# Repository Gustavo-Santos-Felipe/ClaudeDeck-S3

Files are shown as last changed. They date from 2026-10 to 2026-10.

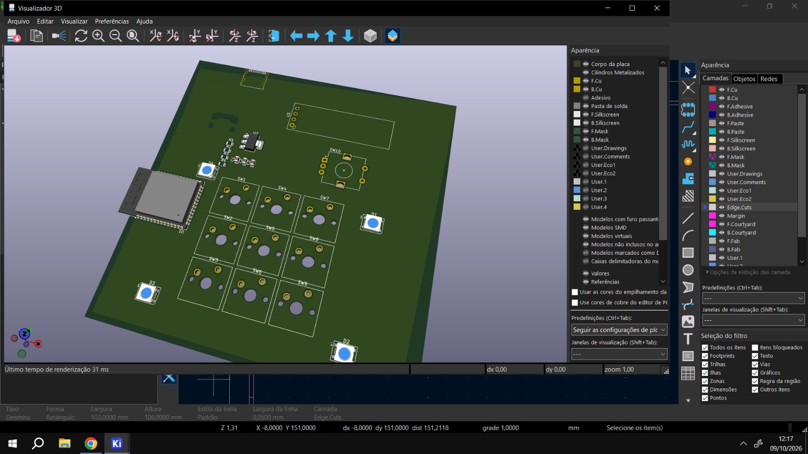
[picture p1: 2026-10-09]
render_3d.png

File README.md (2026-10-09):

# ClaudeDeck-S3
An open-source, ESP32-S3-powered mechanical macropad designed for developer productivity and Claude AI integration. Features 10 hot-swappable mechanical switches with per-key RGB backlighting, a rotary encoder, and an I2C OLED display for real-time status and shortcut navigation.
Render da Placa
20250326_132614-1148x864

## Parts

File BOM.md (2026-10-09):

# ClaudeDeck S3 – bill of materials

<!-- Generated by Half Life from project cmuv6cyex0dys01smc1ebw71v. Edits here are overwritten on the next sync. -->
<!-- Generated: 2026-10-09T17:57:54.359Z -->

> [!NOTE]
> This parts list is mirrored from [Half Life](https://halflife.hackclub.com). Editing it here will not change the platform's copy, and the next sync overwrites this file.

| Week | Tier | Parts funding |
| --- | --- | --- |
| Week 1 | Tier 2 | $65.00 |

| Part | What it's for | Qty | Unit | Total | Vendor |
| --- | --- | --- | --- | --- | --- |
| [ESP32-S3-WROOM-1 / ESP32-S3 N16R8 Dev Board](https://www.mercadolivre.com.br/esp32s3-n16r8-com-16mb-flash-8mb-psram--brinde-cabo-usb/up/MLBU3759855210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) | Main microcontroller, Wi-Fi, and processing logic | 1 | $16.00 | $16.00 | [Mercado Livre BR](https://www.mercadolivre.com.br/esp32s3-n16r8-com-16mb-flash-8mb-psram--brinde-cabo-usb/up/MLBU3759855210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) |
| [Switches](https://www.mercadolivre.com.br/p/MLB2091173212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) | Mechanical keyboard switches for the 3x3 matrix | 1 | $6.00 | $6.00 | [Mercado Livre BR](https://www.mercadolivre.com.br/p/MLB2091173212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) |
| [OLED Display 0.91 inch I2C (128x32)](https://produto.mercadolivre.com.br/MLB-4553164164-display-oled-128x32-pixel-091-polegadas-4-pinos-i2c-_JM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) | Screen to display real-time status and menus | 1 | $11.50 | $11.50 | [Mercado Livre BR](https://produto.mercadolivre.com.br/MLB-4553164164-display-oled-128x32-pixel-091-polegadas-4-pinos-i2c-_JM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) |
| [WS2812B SMD 5050 RGB LEDs](https://www.mercadolivre.com.br/kit-100-unidades-chip-led-rgb-5050-alto-brilho-chip-rgb/up/MLBU1424762403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) | Programmable RGB backlighting | 4 | $5.00 | $20.00 | [Mercado Livre BR](https://www.mercadolivre.com.br/kit-100-unidades-chip-led-rgb-5050-alto-brilho-chip-rgb/up/MLBU1424762403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) |
| [USB-c module](https://www.mercadolivre.com.br/conector-usb-c-31-16-pin-femea-modulo-para-soldagem-pcb/up/MLBU3682374993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) | power distribuic | 1 | $3.00 | $3.00 | [Mercado Livre BR](https://www.mercadolivre.com.br/conector-usb-c-31-16-pin-femea-modulo-para-soldagem-pcb/up/MLBU3682374993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) |
| [encolder](https://www.mercadolivre.com.br/10-encoder-rotativo-com-chave-5-terminais-potenciometro-ec11/up/MLBU1466437144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) | eyboard switches | 1 | $8.00 | $8.00 | [Mercado Livre BR](https://www.mercadolivre.com.br/10-encoder-rotativo-com-chave-5-terminais-potenciometro-ec11/up/MLBU1466437144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) |
| **Parts subtotal** | — | — | — | **$64.50** | — |
| **Tax & shipping** | — | — | — | **$0.00** | — |
| **Total** | — | — | — | **$64.50** | — |

$0.50 left of the tier's funding.

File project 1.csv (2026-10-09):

Id | Designador | Footprint | Quantidade | Designação | Fornecedor e referência
1 | C1, C2 | C_0805_2012Metric | 2 | 10µF
2 | C3 | C_0805_2012Metric | 1 | C
3 | D1, D2, D3, D4 | LED_WS2812B_PLCC4_5.0x5.0mm_P3.2mm | 4 | WS2812B
4 | J1 | USB_C_Receptacle_HRO_TYPE-C-31-M-12 | 1 | USB_C_Receptacle_USB2.0_14P
5 | R1, R2 | R_0805_2012Metric | 2 | 5.1kΩ
6 | R3 | R_0805_2012Metric | 1 | R_US
7 | R4 | R_0805_2012Metric | 1 | 330Ω
8 | SW1, SW2, SW3, SW4, SW5, SW6, SW7, SW8, SW9 | SW_Cherry_MX_1.00u_PCB | 9 | SW_Push
9 | SW10 | RotaryEncoder_Alps_EC12E-Switch_Vertical_H20mm | 1 | RotaryEncoder_Switch
10 | U1 | ESP32-S3-WROOM-1 | 1 | ESP32-S3-WROOM-1
11 | U2 | SOT-223-3_TabPin2 | 1 | AMS1117-3.3
12 | U3 | ER_OLEDM0.91_1x-I2C | 1 | ER_OLEDM0.91_1x-I2C

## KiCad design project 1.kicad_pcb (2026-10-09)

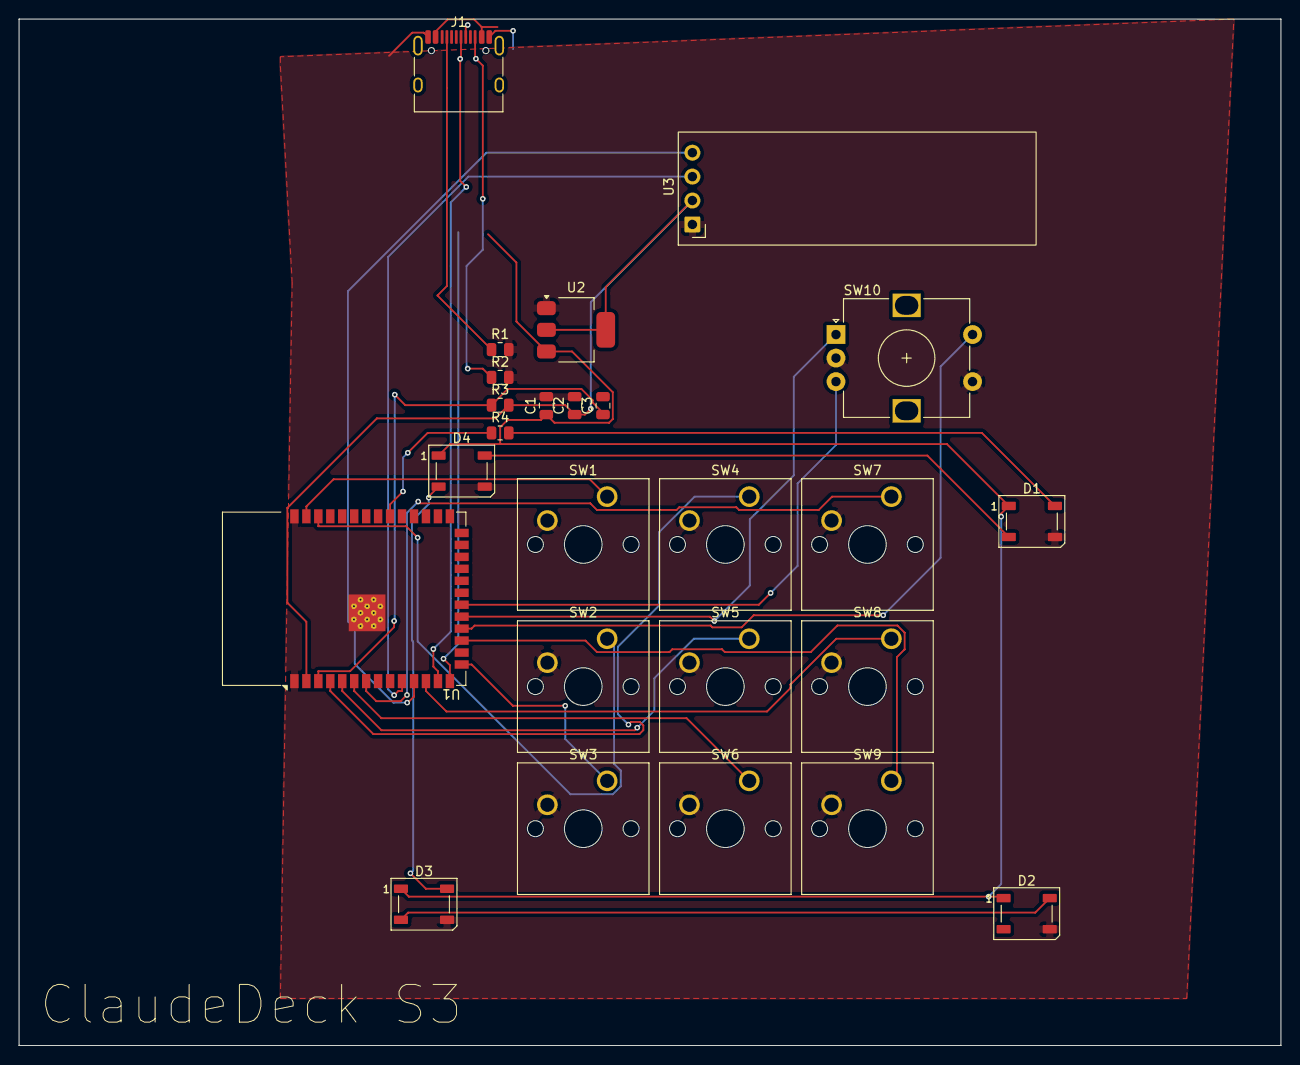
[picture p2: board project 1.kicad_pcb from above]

Board: 2 copper layers, 134.0 x 109.0 mm, 25 parts (0 on the bottom side), 27 nets.

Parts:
C1, C2: 10µF; C_0805_2012Metric
C3: C; C_0805_2012Metric
D1, D2, D3, D4: WS2812B; LED_WS2812B_PLCC4_5.0x5.0mm_P3.2mm
J1: USB_C_Receptacle_USB2.0_14P; USB_C_Receptacle_HRO_TYPE-C-31-M-12
R1, R2: 5.1kΩ; R_0805_2012Metric
R3: R_US; R_0805_2012Metric
R4: 330Ω; R_0805_2012Metric
SW1, SW2, SW3, SW4, SW5, SW6, SW7, SW8, SW9: SW_Push; SW_Cherry_MX_1.00u_PCB
SW10: RotaryEncoder_Switch; RotaryEncoder_Alps_EC12E-Switch_Vertical_H20mm
U1: ESP32-S3-WROOM-1
U2: AMS1117-3.3; SOT-223-3_TabPin2
U3: ER_OLEDM0.91_1x-I2C

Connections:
/+3V3: C2.1, R3.2, U1.2 (3V3), U2.2 (VO), U3.2 (VCC)
/+5V: C1.1, D1.1 (VDD), D2.1 (VDD), D3.1 (VDD), D4.1 (VDD), J1.A4 (VBUS), J1.A9 (VBUS), J1.B4 (VBUS), J1.B9 (VBUS), U2.3 (VI)
/DOUT1: D1.2 (DOUT), D4.4 (DIN)
/DOUT2: D3.4 (DIN), D4.2 (DOUT)
/DOUT3: D2.4 (DIN), D3.2 (DOUT)
/IO1: SW1.1, U1.39 (IO1)
/IO2: SW2.1, U1.38 (IO2)
/IO3: SW3.1, U1.15 (IO3)
/IO4: SW4.1, U1.4 (IO4)
/IO5: SW5.1, U1.5 (IO5)
/IO6: SW6.1, U1.6 (IO6)
/IO7: SW7.1, U1.7 (IO7)
/IO8: SW8.1, U1.12 (IO8)
/IO9: SW9.1, U1.17 (IO9)
/IO10: SW10.S1, U1.18 (IO10)
/IO11: SW10.A, U1.19 (IO11)
/IO12: SW10.B, U1.20 (IO12)
GND: C1.2, C2.2, C3.2, D1.3 (VSS), D2.3 (VSS), D3.3 (VSS), D4.3 (VSS), J1.A1 (GND), J1.A12 (GND), J1.B1 (GND), J1.B12 (GND), R1.2, R2.2, SW1.2, SW2.2, SW3.2, SW4.2, SW5.2, SW6.2, SW7.2, SW8.2, SW9.2, SW10.C, SW10.S2, U1.1 (GND), U1.40 (GND), U1.41 (GND), U2.1 (GND), U3.1 (GND)
unnamed: D1.4 (DIN), R4.2
unnamed: J1.A5 (CC1), R1.1
unnamed: J1.B5 (CC2), R2.1
unnamed: C3.1, R3.1, U1.3 (EN)
unnamed: U1.10 (IO17), U3.3 (SCL)
unnamed: U1.11 (IO18), U3.4 (SDA)
unnamed: R4.1, U1.32 (IO39)
unnamed: J1.B6 (D+), U1.14 (USB_D+)
unnamed: J1.A7 (D-), U1.13 (USB_D-)

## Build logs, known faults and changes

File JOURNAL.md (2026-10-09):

# ClaudeDeck S3 – devlog

<!-- Generated by Half Life from project cmuv6cyex0dys01smc1ebw71v. Edits here are overwritten on the next sync. -->
<!-- Generated: 2026-10-09T15:54:22.577Z -->

> [!NOTE]
> This devlog is mirrored from [Half Life](https://halflife.hackclub.com). Editing it here will not change the platform's copy, and the next sync overwrites this file.

> An open-source, ESP32-S3-powered mechanical macropad designed for developer productivity and Claude AI integration. Features 10 hot-swappable mechanical switches with per-key RGB backlighting, a rotary encoder, and an I2C OLED display for real-time status and shortcut navigation.

| Week | Tier | Hours logged | Entries |
| --- | --- | --- | --- |
| Week 1 | Tier 2 | 16h | 3 |

## Contents

1. [2026-10-05 – Hi community. First, I went through a quick tutorial, since I'm more used to EasyEDA rsrsrs.](#2026-10-05-hi-community-first-i-went-through-a-quick-tutoria)
2. [2026-10-06 – The journey of the past 5 hours has been one of pure dedication to hardware design. What started as an idea for a custom ESP32-S3 macropad began to take real shape in KiCad. The first major milestone](#2026-10-06-the-journey-of-the-past-5-hours-has-been-one-of-p)
3. [2026-10-09 – Building the ClaudeDeck S3: From Initial Routing to a Finished PCB](#2026-10-09-building-the-claudedeck-s3-from-initial-routing-t)

## Design

### 2026-10-05 – Hi community. First, I went through a quick tutorial, since I'm more used to EasyEDA rsrsrs.

**6h**

Hi community. First, I went through a quick tutorial, since I'm more used to EasyEDA rsrsrs.

WhatsApp Image 2026-10-05 at 21.53.50
WhatsApp Image 2026-10-05 at 22.54.29

I started this session aiming to lay out the core components of my ESP32-S3 macropad. Initially, I made a mistake by selecting the bare ESP32-S3 SoC instead of the module. I realized my mistake and reorganized the layout to use the ESP32-S3-WROOM-1 module for easier soldering later.

WhatsApp Image 2026-10-05 at 21.53.50
Next, I tackled the power delivery, connecting a USB-C receptacle to an AMS1117-3.3 LDO. I thought just connecting VBUS and GND was enough, but I learned a crucial hardware lesson today: if someone uses a USB-C to USB-C cable (like a Mac charger), it won't provide 5V unless it detects a device! To solve this, I had to add two separate 5.1kΩ pull-down resistors to the CC1 and CC2 pins.

WhatsApp Image 2026-10-05 at 21.54.15
I also learned that voltage regulators are highly unstable without filters, so I added 10uF ceramic capacitors to the input and output of the LDO (I actually almost used a condenser microphone symbol by accident before fixing it!). To ensure the ESP32 boots properly, I wired a 10kΩ pull-up resistor and a 1uF capacitor to the EN pin.

WhatsApp Image 2026-10-05 at 22.18.10
Finally, I started mapping the mechanical switches using Net Labels (IO1 to IO9) to keep the schematic clean and avoid having messy wires crossing everywhere.

WhatsApp Image 2026-10-05 at 22.57.40

WhatsApp Image 2026-10-05 at 23.07.08

### 2026-10-06 – The journey of the past 5 hours has been one of pure dedication to hardware design. What started as an idea for a custom ESP32-S3 macropad began to take real shape in KiCad. The first major milestone

**5h**

The journey of the past 5 hours has been one of pure dedication to hardware design. What started as an idea for a custom ESP32-S3 macropad began to take real shape in KiCad. The first major milestone was the electrical schematic: integrating the microcontroller, mapping the OLED display, configuring the rotary encoder, and ensuring that the data communication for the LED cascade was perfect.

WhatsApp Image 2026-10-06 at 07.45.08

WhatsApp Image 2026-10-06 at 08.03.31
When transitioning to the physical board design, I faced the classic footprint conflicts. I debugged and resolved each one of them with a clear goal in mind: to ensure that this is a genuinely open-source and easy-to-replicate project. To achieve this, I made a point of standardizing the selection with the industry's most universal components, ensuring compatibility with Cherry MX switches and common SMD resistors.

WhatsApp Image 2026-10-06 at 08.28.27

WhatsApp Image 2026-10-06 at 08.16.28
The most satisfying moment was undoubtedly updating the PCB and successfully placing all the components in the editor without a single error. The logical foundation is solid and validated. The next step is organizing the physical layout of the panel and starting the track routing. The effort in electronics always pays off!

WhatsApp Image 2026-10-06 at 08.45.14

### 2026-10-09 – Building the ClaudeDeck S3: From Initial Routing to a Finished PCB

**5h**

Building the ClaudeDeck S3: From Initial Routing to a Finished PCB
The project began with the goal of designing an open-source, custom 3x3 macropad. The first steps in KiCad involved organizing the switch matrix and routing the initial copper traces. However, the early design lacked a crucial element. As noted in the log, the circuit was "sem MALHA GND" (without a GND copper pour). It was missing the copper fill that acts as a ground plane, which is essential for signal integrity and board stability.

WhatsApp Image 2026-10-07 at 15.57.10
After connecting the components, the 3D viewer was used to check the physical appearance of the board. The software rendered a massive, disproportionate green fiberglass board. The entire circuit and the USB-C connector were surrounded by excessive empty space. This happened because the original board outline was too large. If manufactured in this state, the USB cable would not physically reach the connector.

WhatsApp Image 2026-10-09 at 12.19.22
To fix this, the oversized outline was deleted and a new, compact border was drawn closely around the copper zones. For the board to be practical, mechanical constraints also had to be addressed. This progress was marked by the update stating the board was "AGORA COM FUROS DE FIXAÇÃO" (now with mounting holes). Adding these four corner holes ensured the PCB could be properly secured inside its future 3D-printed enclosure.

WhatsApp Image 2026-10-09 at 12.38.10
With the technical routing complete, the final step involved preparing the design for manufacturing. This was documented with the realization that factories do not read KiCad project files directly; instead, they require "Gerbers". The design was exported into the standard Gerber and drill files and packaged into a ZIP folder, finalizing the design process and making the board ready for production

WhatsApp Image 2026-10-09 at 12.47.51

WhatsApp Image 2026-10-09 at 12.45.18

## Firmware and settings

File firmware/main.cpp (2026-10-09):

#include <Arduino.h>
#include <Keypad.h>
#include <Keyboard.h>
#include <Wire.h>
#include <Adafruit_GFX.h>
#include <Adafruit_SSD1306.h>
#include <FastLED.h>

// --- CONFIGURAÇÃO DOS PINOS (Atualize com os do seu KiCad depois) ---
const byte ROWS = 3; 
const byte COLS = 3; 
byte rowPins[ROWS] = {1, 2, 3}; // Pinos das linhas (ajustar)
byte colPins[COLS] = {4, 5, 6}; // Pinos das colunas (ajustar)

char keys[ROWS][COLS] = {
  {'1','2','3'},
  {'4','5','6'},
  {'7','8','9'}
};
Keypad macropad = Keypad(makeKeymap(keys), rowPins, colPins, ROWS, COLS);

// --- OLED ---
#define SCREEN_WIDTH 128
#define SCREEN_HEIGHT 32
Adafruit_SSD1306 display(SCREEN_WIDTH, SCREEN_HEIGHT, &Wire, -1);

// --- LEDs RGB ---
#define LED_PIN     7 // Pino de dados dos LEDs WS2812B
#define NUM_LEDS    9
CRGB leds[NUM_LEDS];

void setup() {
  Serial.begin(115200);
  Keyboard.begin();
  
  FastLED.addLeds<WS2812B, LED_PIN, GRB>(leds, NUM_LEDS);
  FastLED.setBrightness(50);
  
  if(!display.begin(SSD1306_SWITCHCAPVCC, 0x3C)) {
    Serial.println(F("Falha no OLED"));
  }
  display.clearDisplay();
  display.setTextSize(1);
  display.setTextColor(WHITE);
  display.setCursor(0, 10);
  display.println("ClaudeDeck S3 OK");
  display.display();
}

void loop() {
  char key = macropad.getKey();

  if (key) {
    // Atualiza OLED
    display.clearDisplay();
    display.setCursor(0, 10);
    display.print("Tecla: ");
    display.println(key);
    display.display();

    // Acende LED de feedback
    fill_solid(leds, NUM_LEDS, CRGB::Red);
    FastLED.show();
    
    // Envia o comando USB
    Keyboard.press(key);
    delay(100);
    Keyboard.releaseAll();
    
    // Apaga LED
    fill_solid(leds, NUM_LEDS, CRGB::Black);
    FastLED.show();
  }
}// Código do macropad aqui.

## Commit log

2026-10-12 Sync ClaudeDeck S3 Enclosure from Half Life
2026-10-12 Sync laudeDeck S3 Enclosure from Half Life
2026-10-12 chore: organizar estrutura de pastas do projeto
2026-10-16 Rename hardware/project 1.kicad_sch to electrical diagram.kicad_sch
2026-10-17 Rename WhatsApp Image 2026-10-16 at 23.47.25.jpeg to 3D case top view.jpeg
2026-10-18 Rename WhatsApp Image 2026-10-16 at 23.39.49.jpeg to bottom view of 3D case.jpeg
2026-10-26 Reorganize repo into CAD/PCB and remove Week 2 mentions
2026-10-26 Revise Bill of Materials to table format
    Updated the Bill of Materials section to use a table format for better readability and added links for each item.
